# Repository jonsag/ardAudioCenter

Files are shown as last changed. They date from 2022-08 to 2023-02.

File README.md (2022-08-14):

# ardAudioCenter

An arduino used as a center for audio control.  
Selects between inputs, sets volume, balance etc.  
Controls an FM radio receiver.  
Has an LCD screen.  

## Note

This is a work in progress, but should now be working.  

## Parts list (incomplete)

1 x Arduino (I use and Arduino Nano, ElectroKit#41015511)  
1 x TEA5767 FM radio module, ElectroKit#41015747  
1 x DFPlayer Mini  
1 x CD4052B multiplexer, ElectroKit#40360102  
2 x MCP41010-E/P digital potentiometer, ElectroKit#40351010  
1 x LCD screen, 2x16, ElectroKit#41001407  
1 x Serial interface for LCD, ElectroKit#41011443  
2 x Rotary encoder, ElectroKit#41015725

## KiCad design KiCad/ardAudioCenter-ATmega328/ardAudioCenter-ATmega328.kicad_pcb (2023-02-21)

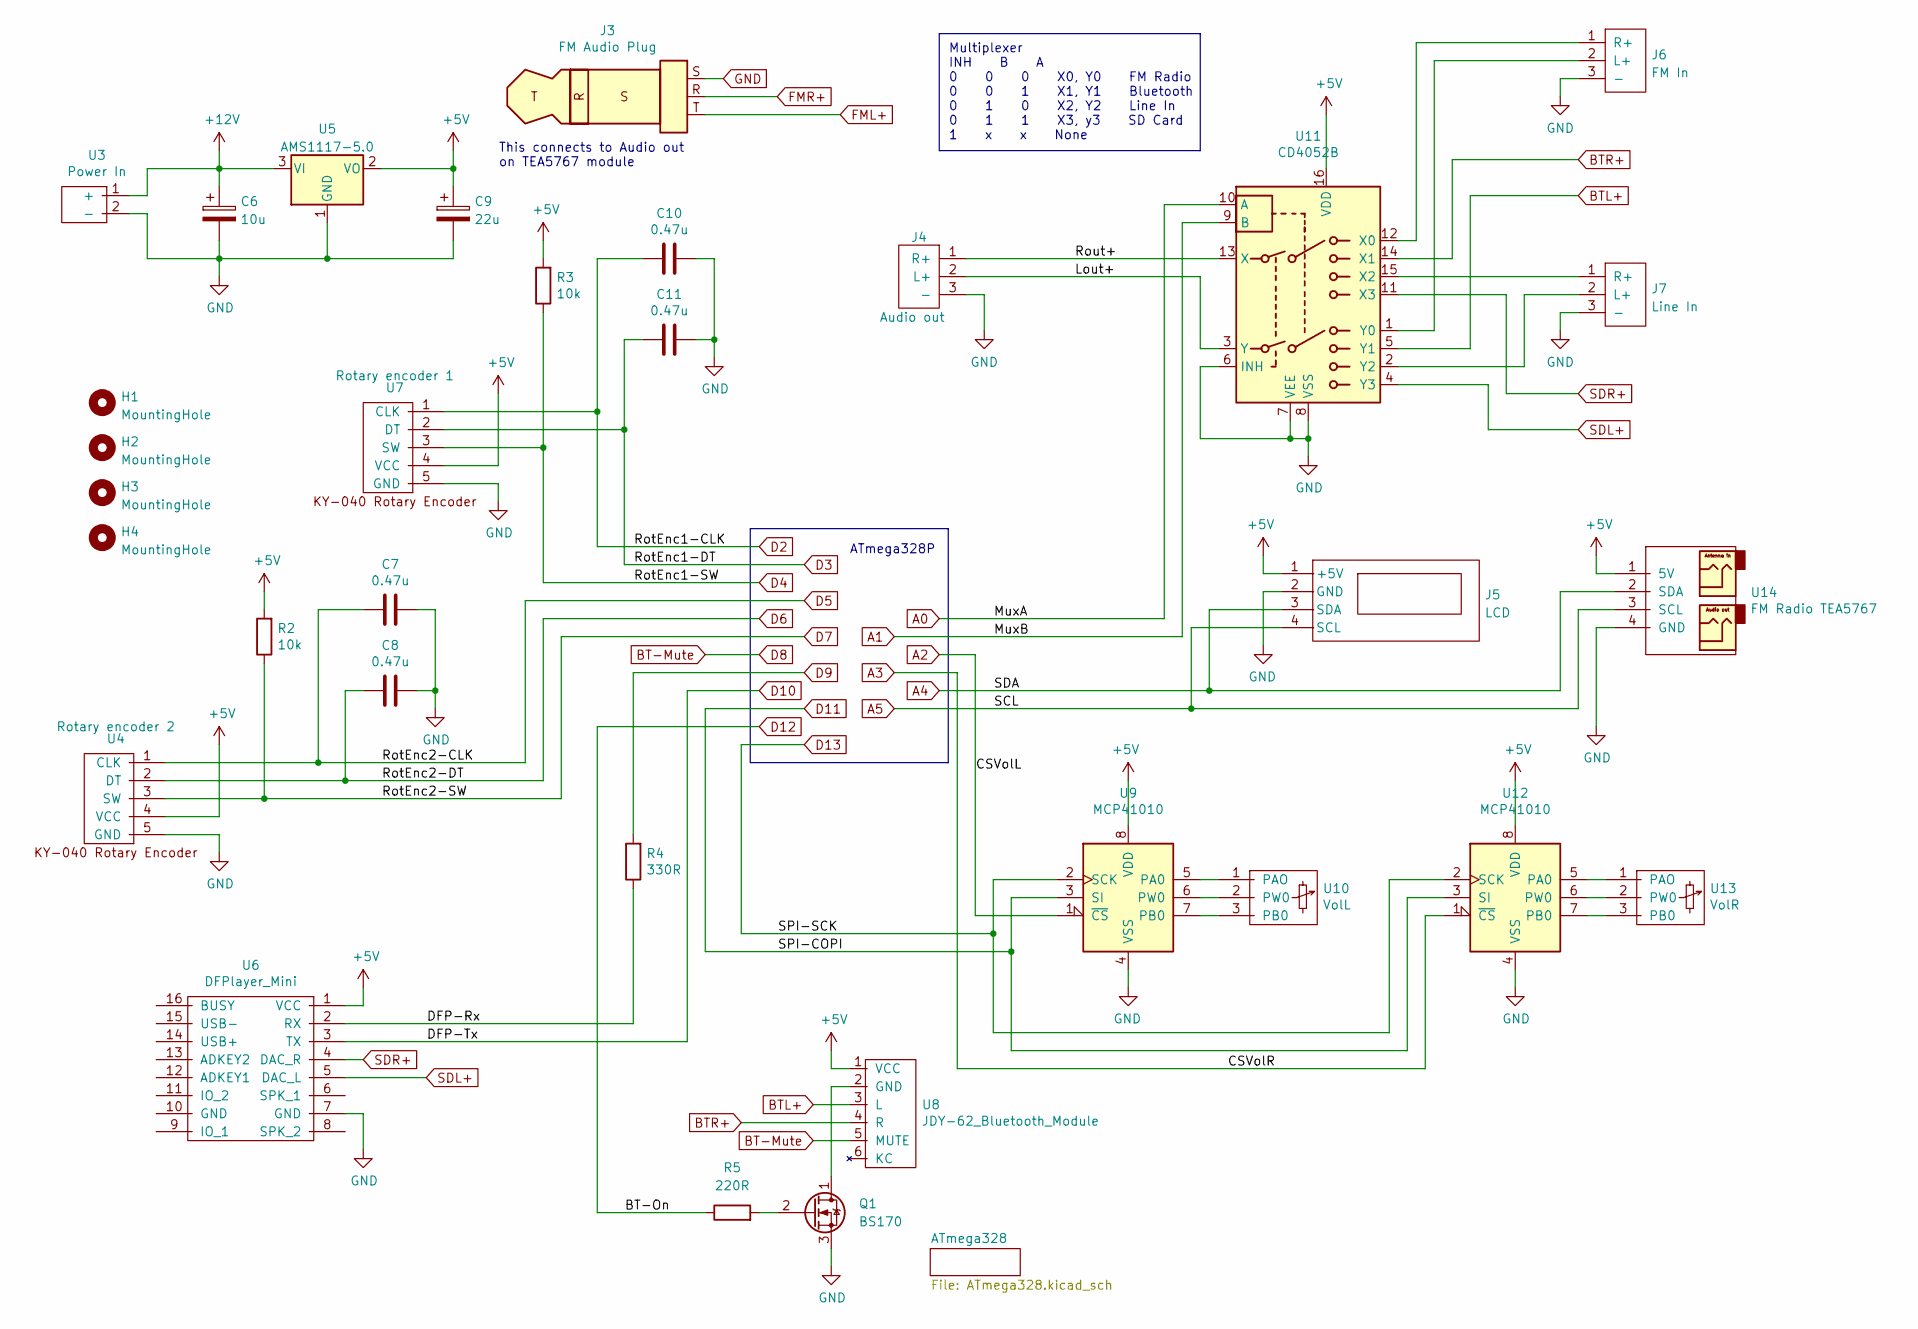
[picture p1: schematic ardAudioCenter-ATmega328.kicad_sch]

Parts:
C6: 10u; CP_Radial_D5.0mm_P2.00mm_larger
C7, C8, C10, C11: 0.47u; C_Disc_D7.5mm_W2.5mm_P5.00mm_larger
C9: 22u; CP_Radial_D5.0mm_P2.00mm_larger
H1, H2, H3, H4: MountingHole; MountingHole_3.5mm
J3: FM Audio Plug
J4: Audio out; 3-pin JST Audio
J5: LCD; 4-pin JST LCD
J6: FM In; 3-pin JST Audio
J7: Line In; 3-pin JST Audio
Q1: BS170; TO-92_Inline_Wide_large
R2, R3: 10k; R_Axial_DIN0207_L6.3mm_D2.5mm_P10.16mm_Horizontal_larger_pa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
R4: 330R; R_Axial_DIN0207_L6.3mm_D2.5mm_P10.16mm_Horizontal_larger_pa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
R5: 220R; R_Axial_DIN0207_L6.3mm_D2.5mm_P10.16mm_Horizontal_larger_pa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
U3: Power In; 2-pole_power_in_screw_terminal
U4: Rotary encoder 2; 5-pin JST Rotary Encoder
U5: AMS1117-5.0; SOT-223-3_TabPin2
U6: DFPlayer_Mini; 8-pin JST DFPlayer Mini
U7: Rotary encoder 1; 5-pin JST Rotary Encoder
U8: JDY-62_Bluetooth_Module; 6-pin JST JDY-62 Bluetooth
U9, U12: MCP41010; DIP-8_W7.62mm_Socket_w_dip_packet_LongPads
U10: VolL; 3-pin JST Potentiometer
U11: CD4052B; DIP-16_W7.62mm_LongPads w socket
U13: VolR; 3-pin JST Potentiometer
U14: FM Radio TEA5767; 4-pin JST TEA5767 FM Radio

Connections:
+5V: C9.1, J5.1 (+5V), R2.2, R3.2, U4.4 (VCC), U5.2 (VO), U6.1 (VCC), U7.4 (VCC), U8.1 (VCC), U9.8 (VDD), U11.16 (VDD), U12.8 (VDD), U14.1 (5V); also elsewhere on the board
+12V: C6.1, U3.1 (+), U5.3 (VI)
/DFP-Rx: R4.1, U6.2 (RX)
/Lout+: J4.2 (L+), U11.3 (Y)
/Rout+: J4.1 (R+), U11.13 (X)
A0: U11.10 (A); also elsewhere on the board
A1: U11.9 (B); also elsewhere on the board
A2: U9.1 (~CS); also elsewhere on the board
A3: U12.1 (~CS); also elsewhere on the board
A4: J5.3 (SDA), U14.2 (SDA); also elsewhere on the board
A5: J5.4 (SCL), U14.3 (SCL); also elsewhere on the board
BT-Mute: U8.5 (MUTE); also elsewhere on the board
BTL+: U8.3 (L), U11.5 (Y1)
BTR+: U8.4 (R), U11.14 (X1)
D2: C10.1, U7.1 (CLK); also elsewhere on the board
D3: C11.2, U7.2 (DT); also elsewhere on the board
D4: R3.1, U7.3 (SW); also elsewhere on the board
D5: C7.1, U4.1 (CLK); also elsewhere on the board
D6: C8.2, U4.2 (DT); also elsewhere on the board
D7: R2.1, U4.3 (SW); also elsewhere on the board
D9: R4.2; also elsewhere on the board
D10: U6.3 (TX); also elsewhere on the board
D11: U9.3 (SI), U12.3 (SI); also elsewhere on the board
D12: R5.1; also elsewhere on the board
D13: U9.2 (SCK), U12.2 (SCK); also elsewhere on the board
GND: C6.2, C7.2, C8.1, C9.2, C10.2, C11.1, J4.3 (-), J5.2 (GND), J6.3 (-), J7.3 (-), Q1.3 (S), U3.2 (-), U4.5 (GND), U5.1 (GND), U6.7 (GND), U7.5 (GND), U9.4 (VSS), U11.6 (INH), U11.7 (VEE), U11.8 (VSS), U12.4 (VSS), U14.4 (GND); also elsewhere on the board
unnamed: J6.1 (R+), U11.12 (X0)
unnamed: J6.2 (L+), U11.1 (Y0)
unnamed: J7.1 (R+), U11.15 (X2)
unnamed: J7.2 (L+), U11.2 (Y2)
unnamed: Q1.1 (D), U8.2 (GND)
unnamed: Q1.2 (G), R5.2
unnamed: U9.5 (PA0), U10.1 (PAO)
unnamed: U9.6 (PW0), U10.2 (PW0)
unnamed: U9.7 (PB0), U10.3 (PB0)
unnamed: U12.5 (PA0), U13.1 (PAO)
unnamed: U12.6 (PW0), U13.2 (PW0)
unnamed: U12.7 (PB0), U13.3 (PB0)
SDL+: U6.5 (DAC_L), U11.4 (Y3)
SDR+: U6.4 (DAC_R), U11.11 (X3)

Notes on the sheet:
This connects to Audio out on TEA5767 module
ATmega328P
Multiplexer INH B A 0 0 0 X0, Y0 FM Radio 0 0 1 X1, Y1 Bluetooth 0 1 0 X2, Y2 Line In 0 1 1 X3, y3 SD Card 1 x x None

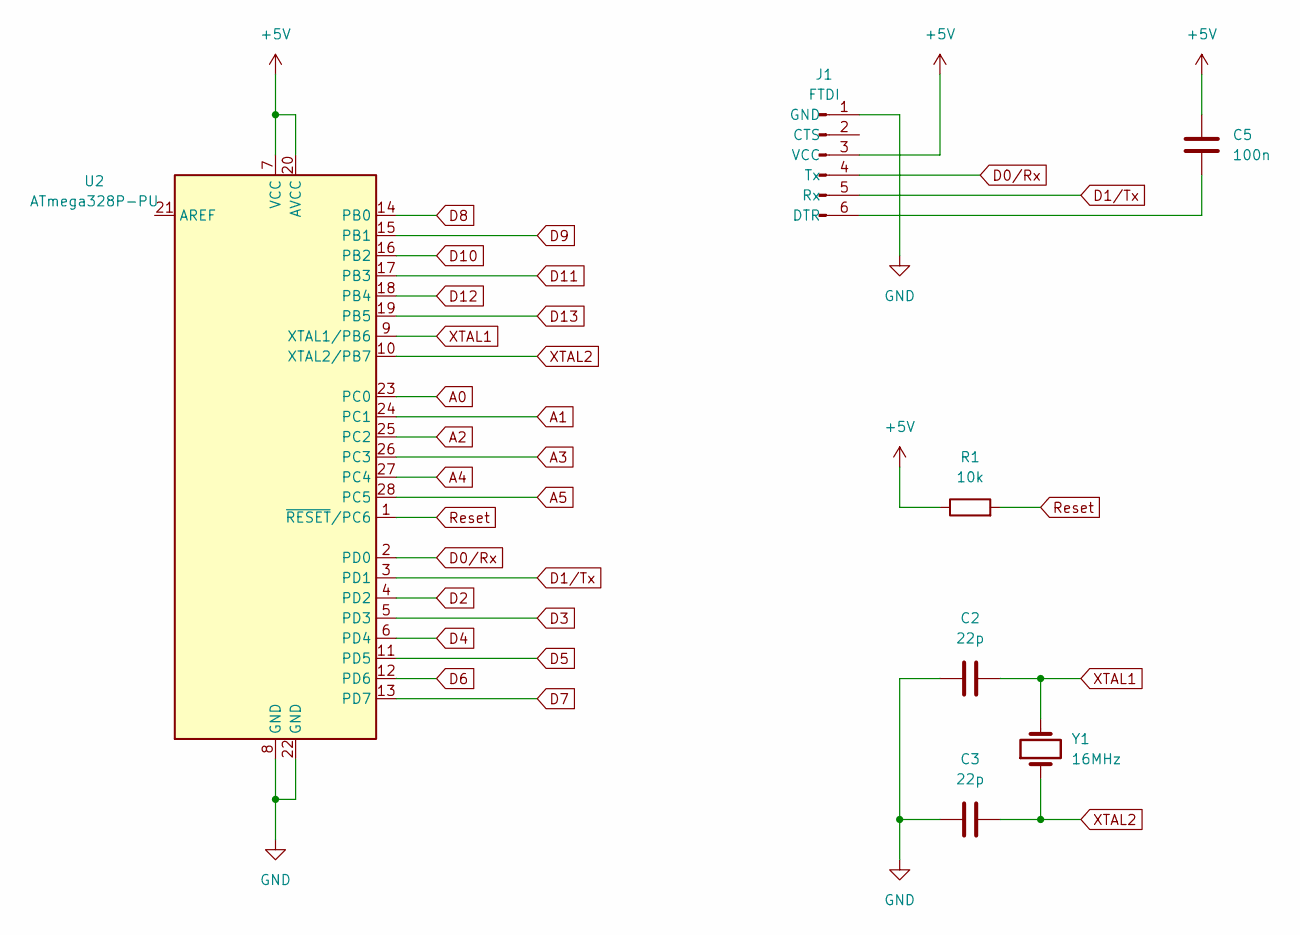
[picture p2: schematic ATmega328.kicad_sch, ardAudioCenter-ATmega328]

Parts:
C2, C3: 22p; C_Disc_D3.0mm_W1.6mm_P2.50mm_larg
C5: 100n; C_Disc_D3.0mm_W1.6mm_P2.50mm_larg
J1: FTDI; 6-pin FTDI Programmer PinSocket large
R1: 10k; R_Axial_DIN0207_L6.3mm_D2.5mm_P10.16mm_Horizontal_larger_pa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
U2: ATmega328P-PU; DIP-28_W7.62mm_LongPads w socket
Y1: 16MHz; Crystal_HC49-4H_Vertical_large

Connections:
+5V: C5.2, J1.3 (VCC), R1.1, U2.7 (VCC), U2.20 (AVCC); also elsewhere on the board
A0: U2.23 (PC0); also elsewhere on the board
A1: U2.24 (PC1); also elsewhere on the board
A2: U2.25 (PC2); also elsewhere on the board
A3: U2.26 (PC3); also elsewhere on the board
A4: U2.27 (PC4); also elsewhere on the board
A5: U2.28 (PC5); also elsewhere on the board
BT-Mute: U2.14 (PB0); also elsewhere on the board
D0/Rx: J1.4 (Tx), U2.2 (PD0)
D1/Tx: J1.5 (Rx), U2.3 (PD1)
D2: U2.4 (PD2); also elsewhere on the board
D3: U2.5 (PD3); also elsewhere on the board
D4: U2.6 (PD4); also elsewhere on the board
D5: U2.11 (PD5); also elsewhere on the board
D6: U2.12 (PD6); also elsewhere on the board
D7: U2.13 (PD7); also elsewhere on the board
D9: U2.15 (PB1); also elsewhere on the board
D10: U2.16 (PB2); also elsewhere on the board
D11: U2.17 (PB3); also elsewhere on the board
D12: U2.18 (PB4); also elsewhere on the board
D13: U2.19 (PB5); also elsewhere on the board
GND: C2.1, C3.1, J1.1 (GND), U2.8 (GND), U2.22 (GND); also elsewhere on the board
unnamed: C5.1, J1.6 (DTR)
Reset: R1.2, U2.1 (~RESET/PC6)
XTAL1: C2.2, U2.9 (XTAL1/PB6), Y1.2
XTAL2: C3.2, U2.10 (XTAL2/PB7), Y1.1

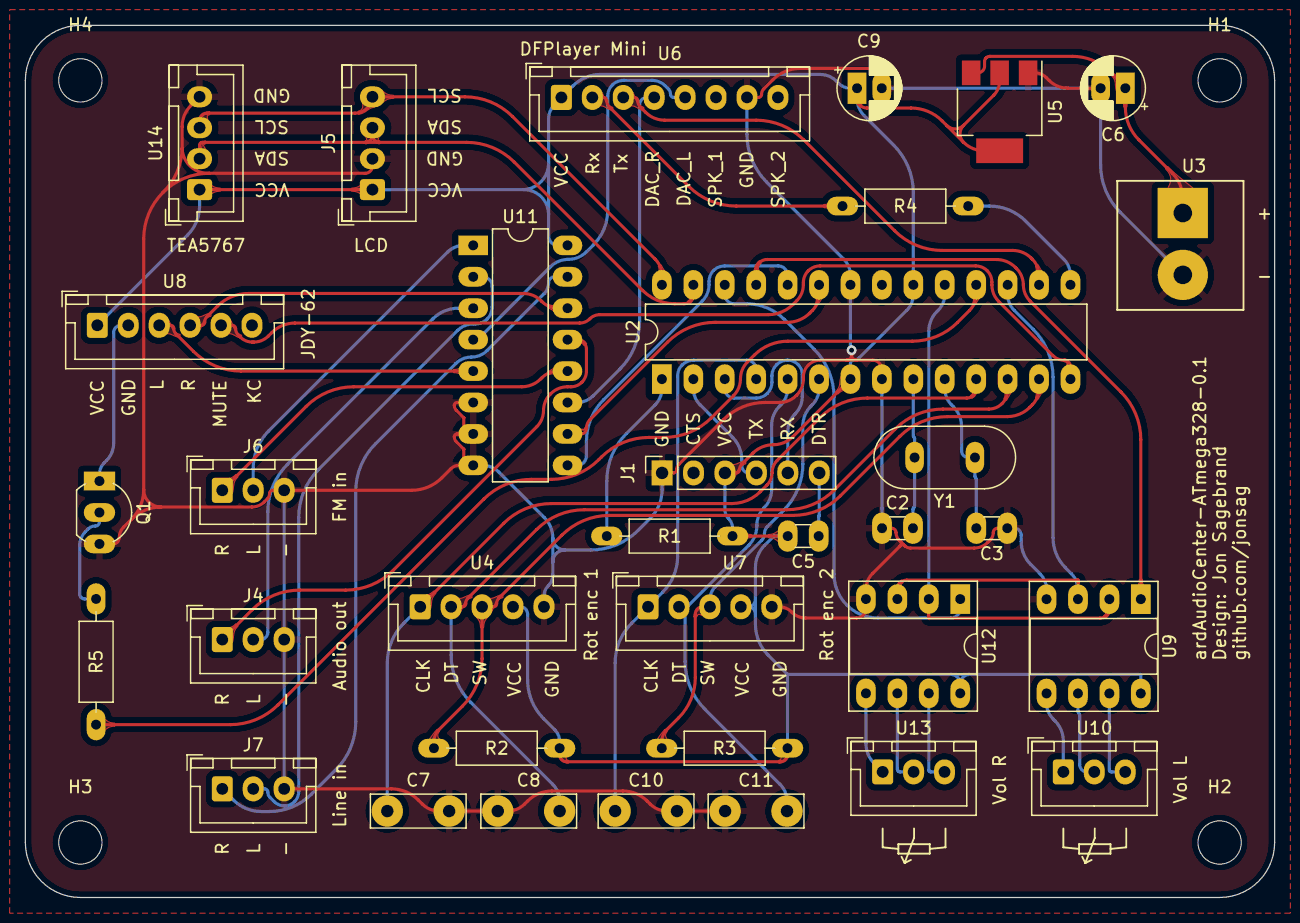
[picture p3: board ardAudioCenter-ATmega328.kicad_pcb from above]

Board: 2 copper layers, 101.0 x 70.5 mm, 38 parts (0 on the bottom side), 46 nets.

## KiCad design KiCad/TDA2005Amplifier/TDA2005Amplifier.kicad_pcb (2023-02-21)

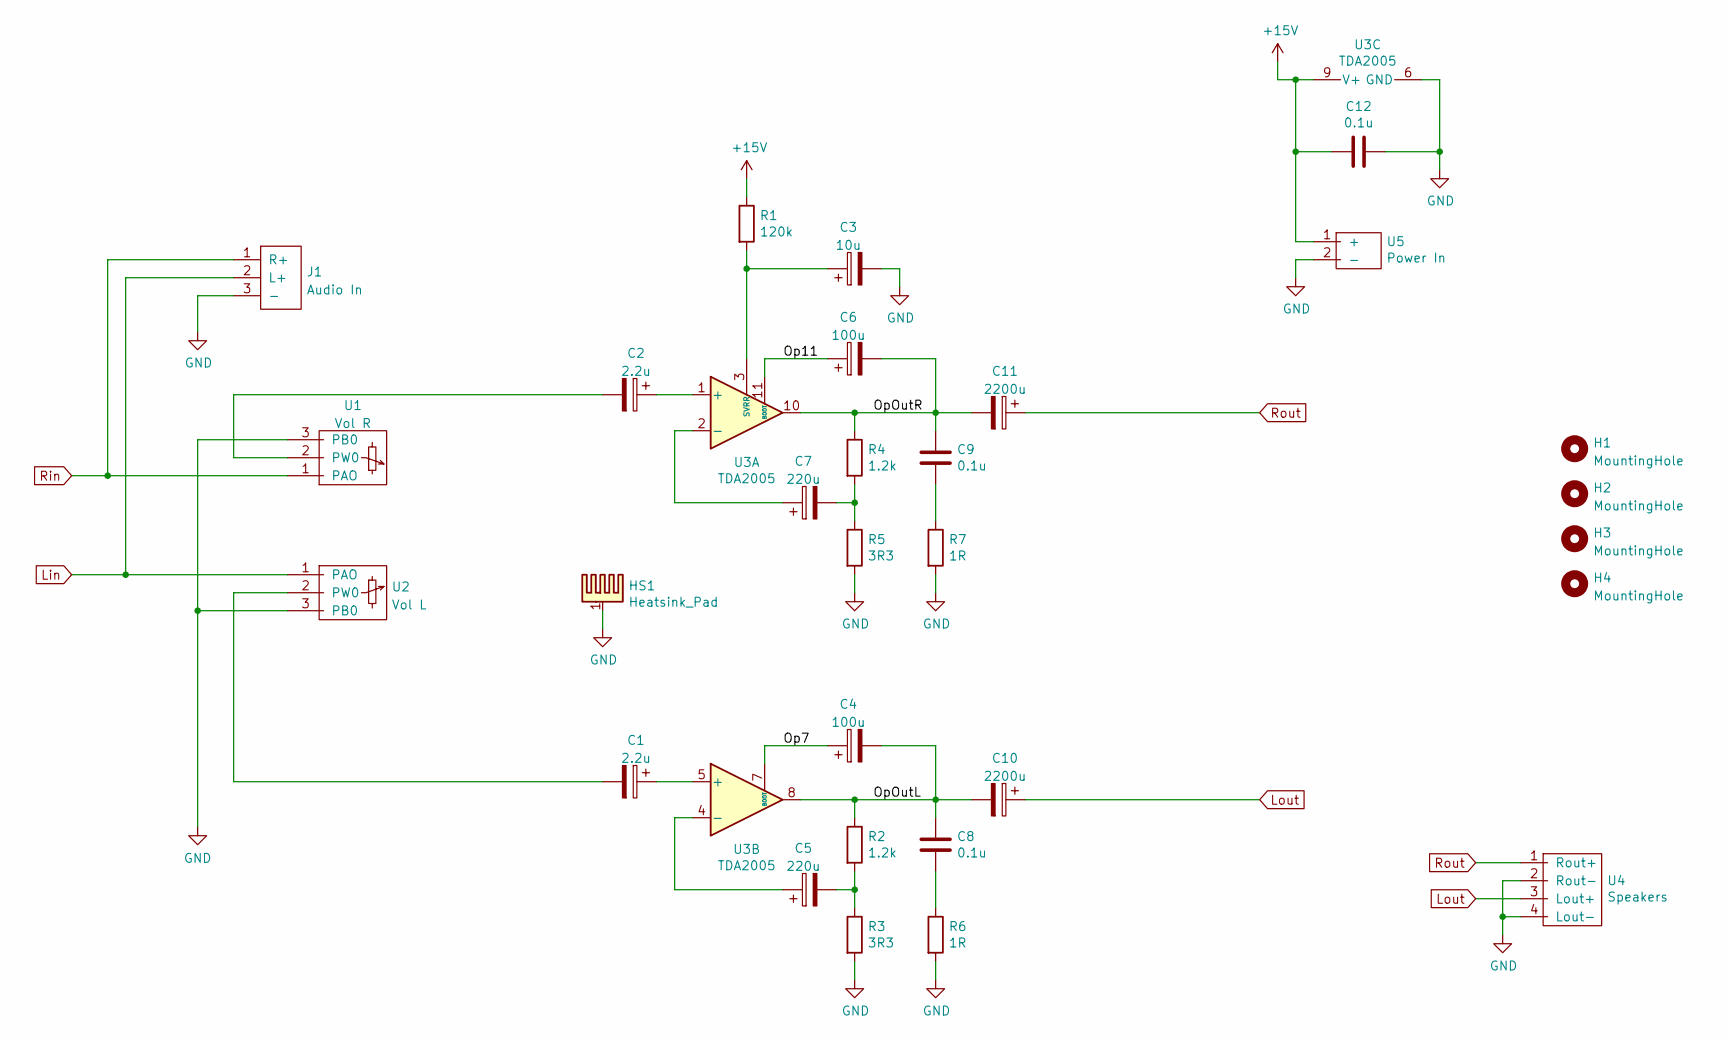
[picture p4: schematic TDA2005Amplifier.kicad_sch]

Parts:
C1, C2: 2.2u; CP_Radial_D5.0mm_P2.00mm_larger
C3: 10u; CP_Radial_D5.0mm_P2.00mm_larger
C4, C6: 100u; CP_Radial_D5.0mm_P2.50mm_larger_pads
C5, C7: 220u; CP_Radial_D8.0mm_P3.50mm_large
C8, C9, C12: 0.1u; C_Disc_D7.5mm_W2.5mm_P5.00mm_larger
C10, C11: 2200u; CP_Radial_D13.0mm_P5.00mm_larger
H1, H2, H3, H4: MountingHole; MountingHole_3.2mm_M3
HS1: Heatsink_Pad; EK-41002859
J1: Audio In; 3-pin JST Audio
R1: 120k; R_Axial_DIN0414_L11.9mm_D4.5mm_P15.24mm_Horizontal_larger
R2, R4: 1.2k; R_Axial_DIN0414_L11.9mm_D4.5mm_P15.24mm_Horizontal_larger
R3, R5: 3R3; R_Axial_DIN0414_L11.9mm_D4.5mm_P15.24mm_Horizontal_larger
R6, R7: 1R; R_Axial_DIN0414_L11.9mm_D4.5mm_P15.24mm_Horizontal_larger
U1: Vol R; 3-pin JST Potentiometer
U2: Vol L; 3-pin JST Potentiometer
U3: TDA2005; TO-220-11_P3.4x5.08mm_StaggerOdd_Lead4.85mm_Vertical_large
U4: Speakers; 4-pole_screw_terminal_RL_output
U5: Power In; 2-pole_power_in_screw_terminal

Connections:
+15V: C12.2, R1.1, U3.9 (V+), U5.1 (+)
/Op7: C4.1, U3.7 (BOOT)
/Op11: C6.1, U3.11 (BOOT)
/OpOutL: C4.2, C8.1, C10.2, R2.1, U3.8
/OpOutR: C6.2, C9.1, C11.2, R4.1, U3.10
GND: C3.2, C12.1, HS1.1, J1.3 (-), R3.2, R5.2, R6.2, R7.2, U1.3 (PB0), U2.3 (PB0), U3.6 (GND), U4.2 (Rout-), U4.4 (Lout-), U5.2 (-)
Lin: J1.2 (L+), U2.1 (PAO)
Lout: C10.1, U4.3 (Lout+)
unnamed: C1.1, U3.5 (+)
unnamed: C1.2, U2.2 (PW0)
unnamed: C2.1, U3.1 (+)
unnamed: C2.2, U1.2 (PW0)
unnamed: C3.1, R1.2, U3.3 (SVRR)
unnamed: C5.1, U3.4 (-)
unnamed: C5.2, R2.2, R3.1
unnamed: C7.1, U3.2 (-)
unnamed: C7.2, R4.2, R5.1
unnamed: C8.2, R6.1
unnamed: C9.2, R7.1
Rin: J1.1 (R+), U1.1 (PAO)
Rout: C11.1, U4.1 (Rout+)

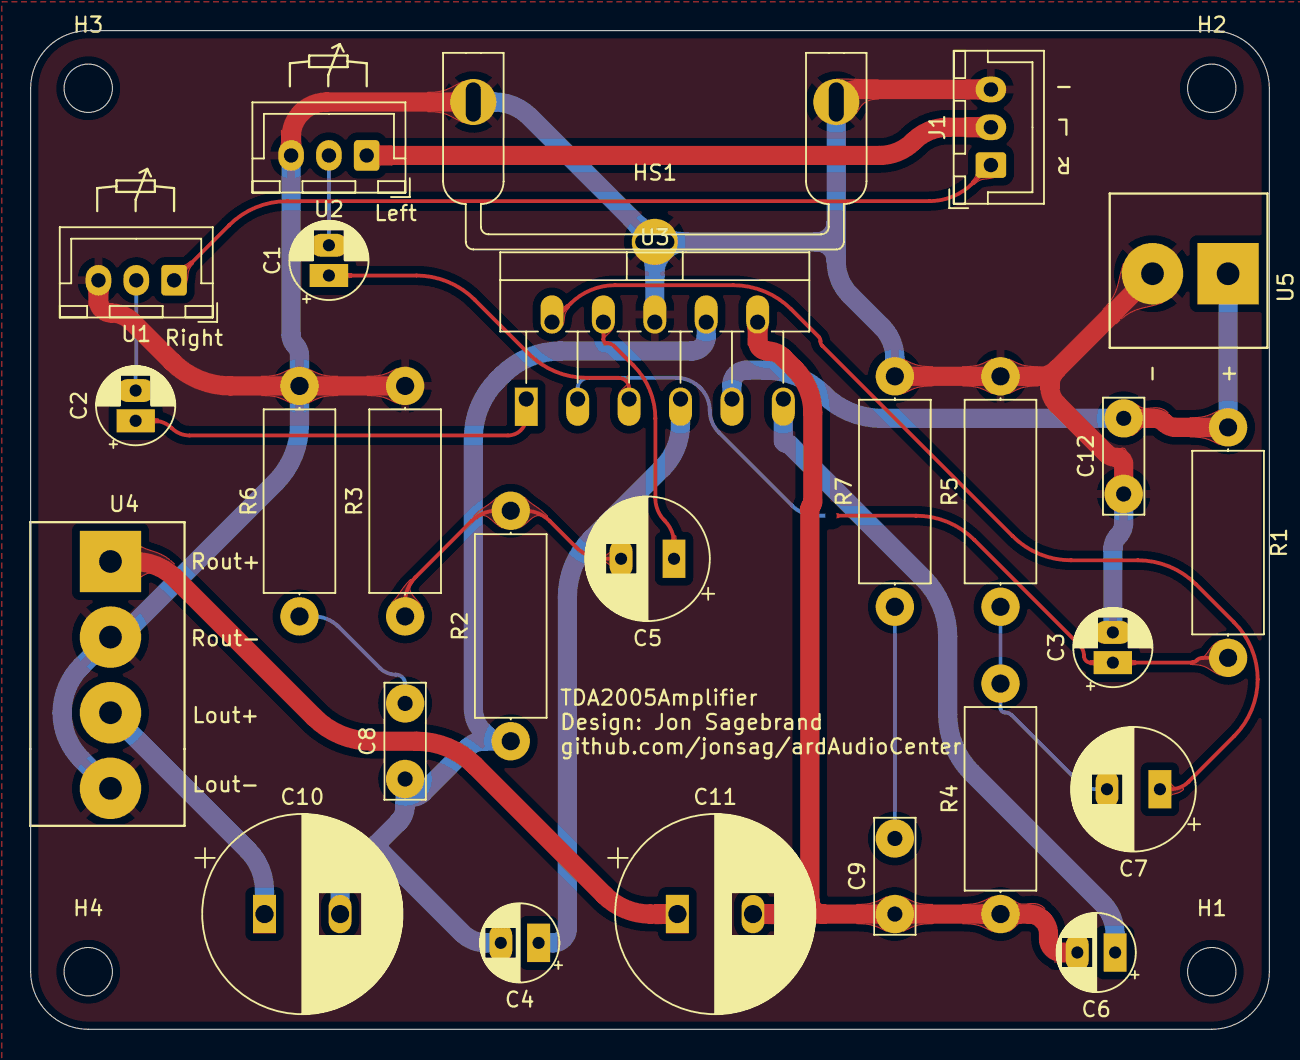
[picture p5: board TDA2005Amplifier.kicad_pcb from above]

Board: 2 copper layers, 81.9 x 66.0 mm, 30 parts (0 on the bottom side), 21 nets.

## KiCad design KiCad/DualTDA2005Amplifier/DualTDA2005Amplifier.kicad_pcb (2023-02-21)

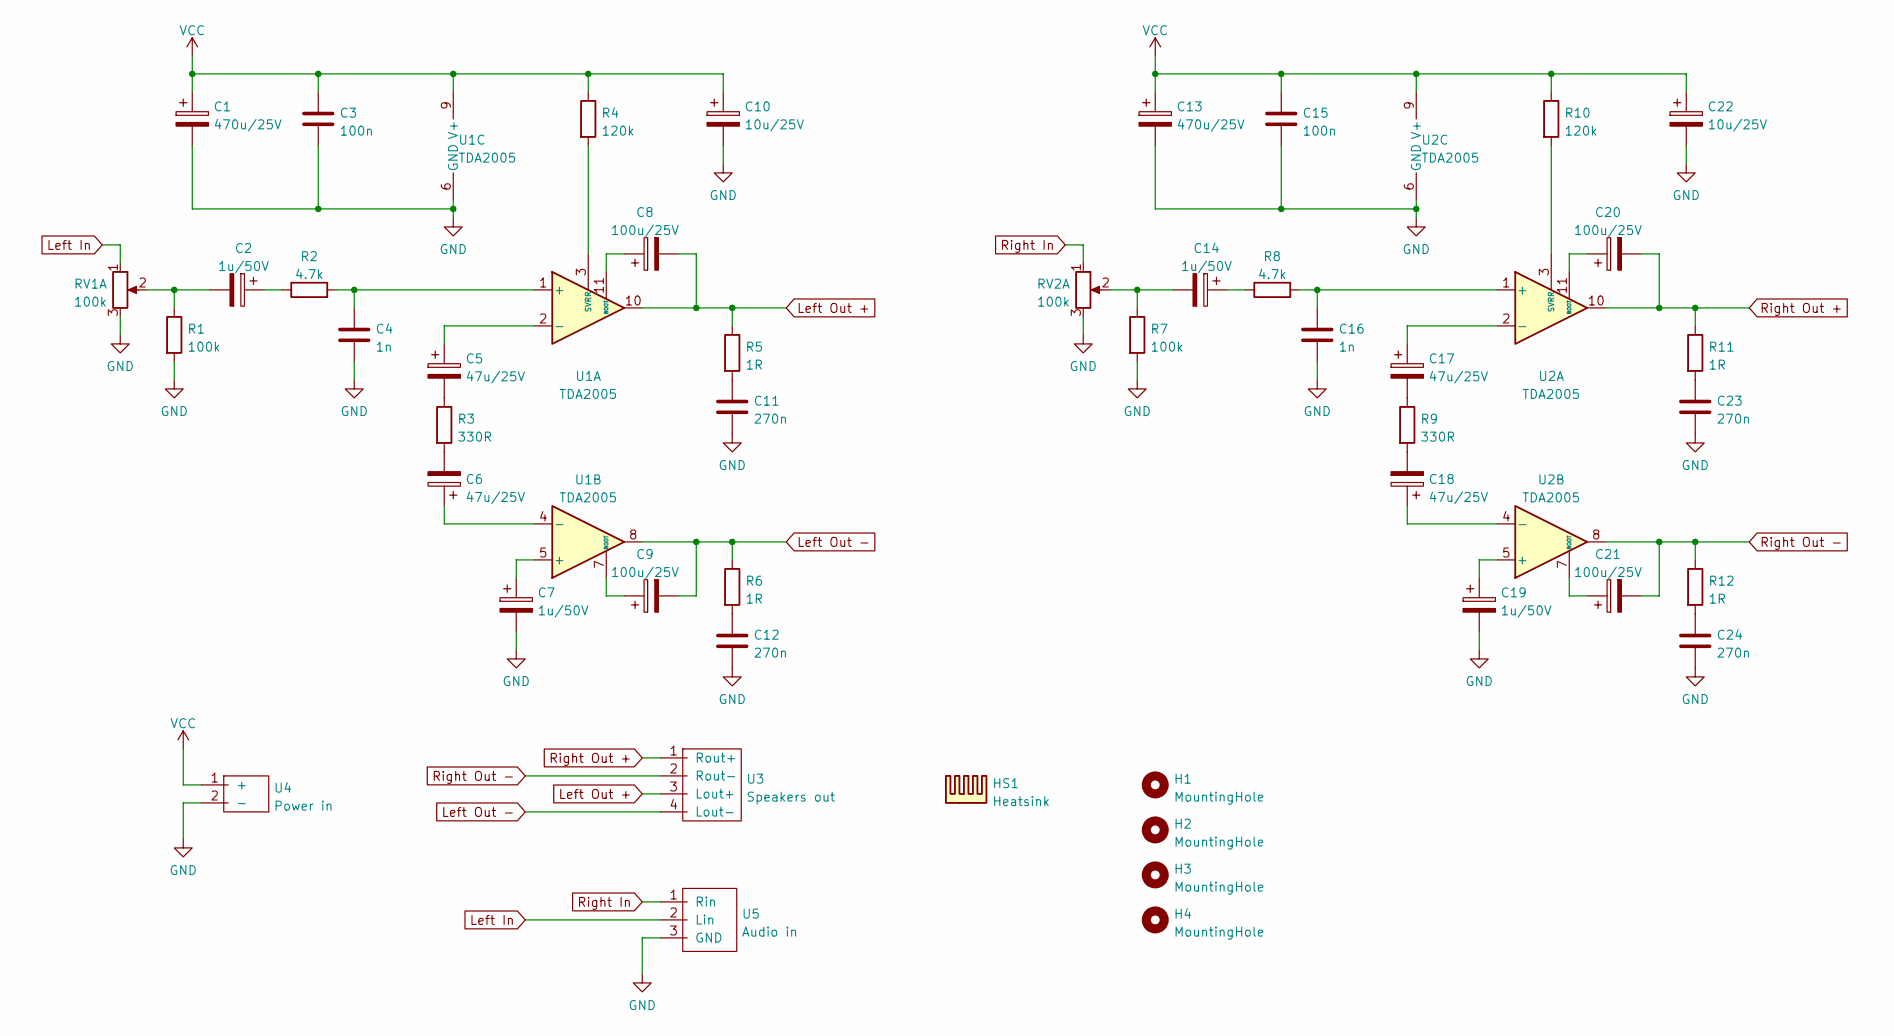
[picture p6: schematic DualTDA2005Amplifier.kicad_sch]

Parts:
C1, C13: 470u/25V; CP_Radial_D10.0mm_P5.00mm_larger
C2, C7, C14, C19: 1u/50V; CP_Radial_D5.0mm_P2.00mm_larger
C3, C15: 100n; C_Rect_L7.2mm_W2.5mm_P5.00mm_FKS2_FKP2_MKS2_MKP2 large
C4, C16: 1n; C_Rect_L7.2mm_W2.5mm_P5.00mm_FKS2_FKP2_MKS2_MKP2 large
C5, C6, C17, C18: 47u/25V; CP_Radial_D5.0mm_P2.00mm_larger
C8, C9, C20, C21: 100u/25V; CP_Radial_D6.3mm_P2.50mm_large
C10, C22: 10u/25V; CP_Radial_D5.0mm_P2.00mm_larger
C11, C12, C23, C24: 270n; C_Rect_L7.2mm_W3.5mm_P5.00mm_FKS2_FKP2_MKS2_MKP2 large
H1, H2, H3, H4: MountingHole; MountingHole_3.2mm_M3
HS1: Heatsink; Heatsink SK81 100x37.5x15
R1, R7: 100k; R_Axial_DIN0207_L6.3mm_D2.5mm_P10.16mm_Horizontal_larger_pa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
R2, R8: 4.7k; R_Axial_DIN0207_L6.3mm_D2.5mm_P10.16mm_Horizontal_larger_pa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
R3, R9: 330R; R_Axial_DIN0207_L6.3mm_D2.5mm_P10.16mm_Horizontal_larger_pa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
R4, R10: 120k; R_Axial_DIN0207_L6.3mm_D2.5mm_P10.16mm_Horizontal_larger_pa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
R5, R6, R11, R12: 1R; R_Axial_DIN0207_L6.3mm_D2.5mm_P10.16mm_Horizontal_larger_pa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
RV1, RV2: 100k; 3-pin JST Potentiometer
U1, U2: TDA2005; TO-220-11_P3.4x5.08mm_StaggerOdd_Lead4.85mm_Vertical_large
U3: Speakers out; 4-pole_screw_terminal_RL_output
U4: Power in; 2-pole_power_in_screw_terminal
U5: Audio in; 3-pin JST Audio

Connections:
GND: C1.2, C3.2, C4.2, C7.2, C10.2, C11.2, C12.2, C13.2, C15.2, C16.2, C19.2, C22.2, C23.2, C24.2, R1.2, R7.2, RV1.3, RV2.3, U1.6 (GND), U2.6 (GND), U4.2 (-), U5.3 (GND)
Left In: RV1.1, U5.2 (Lin)
Left Out +: C8.2, R5.1, U1.10, U3.3 (Lout+)
Left Out -: C9.2, R6.1, U1.8, U3.4 (Lout-)
unnamed: C2.1, R2.1
unnamed: C2.2, R1.1, RV1.2
unnamed: C4.1, R2.2, U1.1 (+)
unnamed: C5.1, U1.2 (-)
unnamed: C5.2, R3.1
unnamed: C6.1, U1.4 (-)
unnamed: C6.2, R3.2
unnamed: C7.1, U1.5 (+)
unnamed: C8.1, U1.11 (BOOT)
unnamed: C9.1, U1.7 (BOOT)
unnamed: C11.1, R5.2
unnamed: C12.1, R6.2
unnamed: C14.1, R8.1
unnamed: C14.2, R7.1, RV2.2
unnamed: C16.1, R8.2, U2.1 (+)
unnamed: C17.1, U2.2 (-)
unnamed: C17.2, R9.1
unnamed: C18.1, U2.4 (-)
unnamed: C18.2, R9.2
unnamed: C19.1, U2.5 (+)
unnamed: C20.1, U2.11 (BOOT)
unnamed: C21.1, U2.7 (BOOT)
unnamed: C23.1, R11.2
unnamed: C24.1, R12.2
unnamed: R4.2, U1.3 (SVRR)
unnamed: R10.2, U2.3 (SVRR)
Right In: RV2.1, U5.1 (Rin)
Right Out +: C20.2, R11.1, U2.10, U3.1 (Rout+)
Right Out -: C21.2, R12.1, U2.8, U3.2 (Rout-)
VCC: C1.1, C3.1, C10.1, C13.1, C15.1, C22.1, R4.1, R10.1, U1.9 (V+), U2.9 (V+), U4.1 (+)

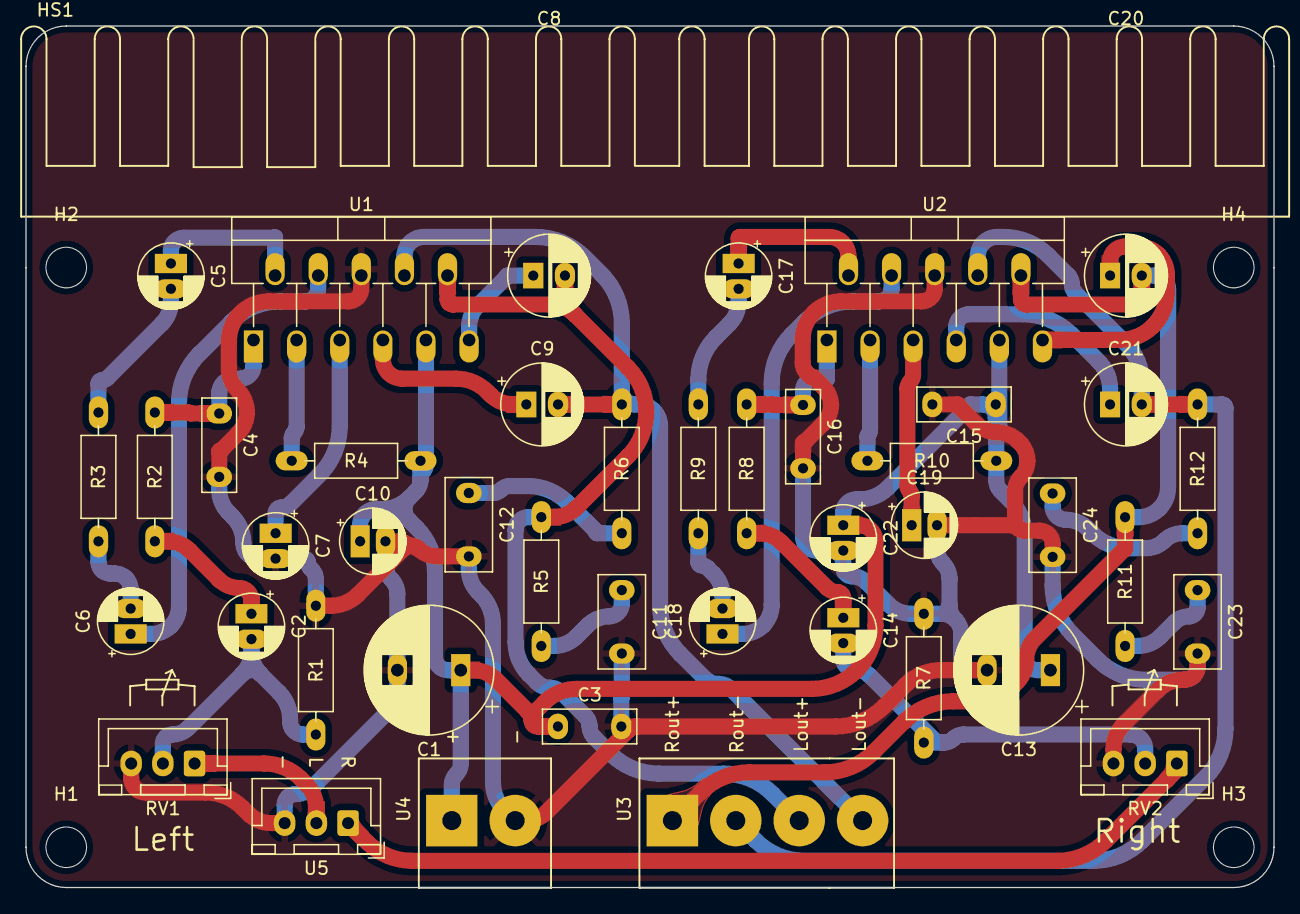
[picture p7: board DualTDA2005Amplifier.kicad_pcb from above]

Board: 2 copper layers, 98.4 x 67.9 mm, 48 parts (0 on the bottom side), 34 nets.

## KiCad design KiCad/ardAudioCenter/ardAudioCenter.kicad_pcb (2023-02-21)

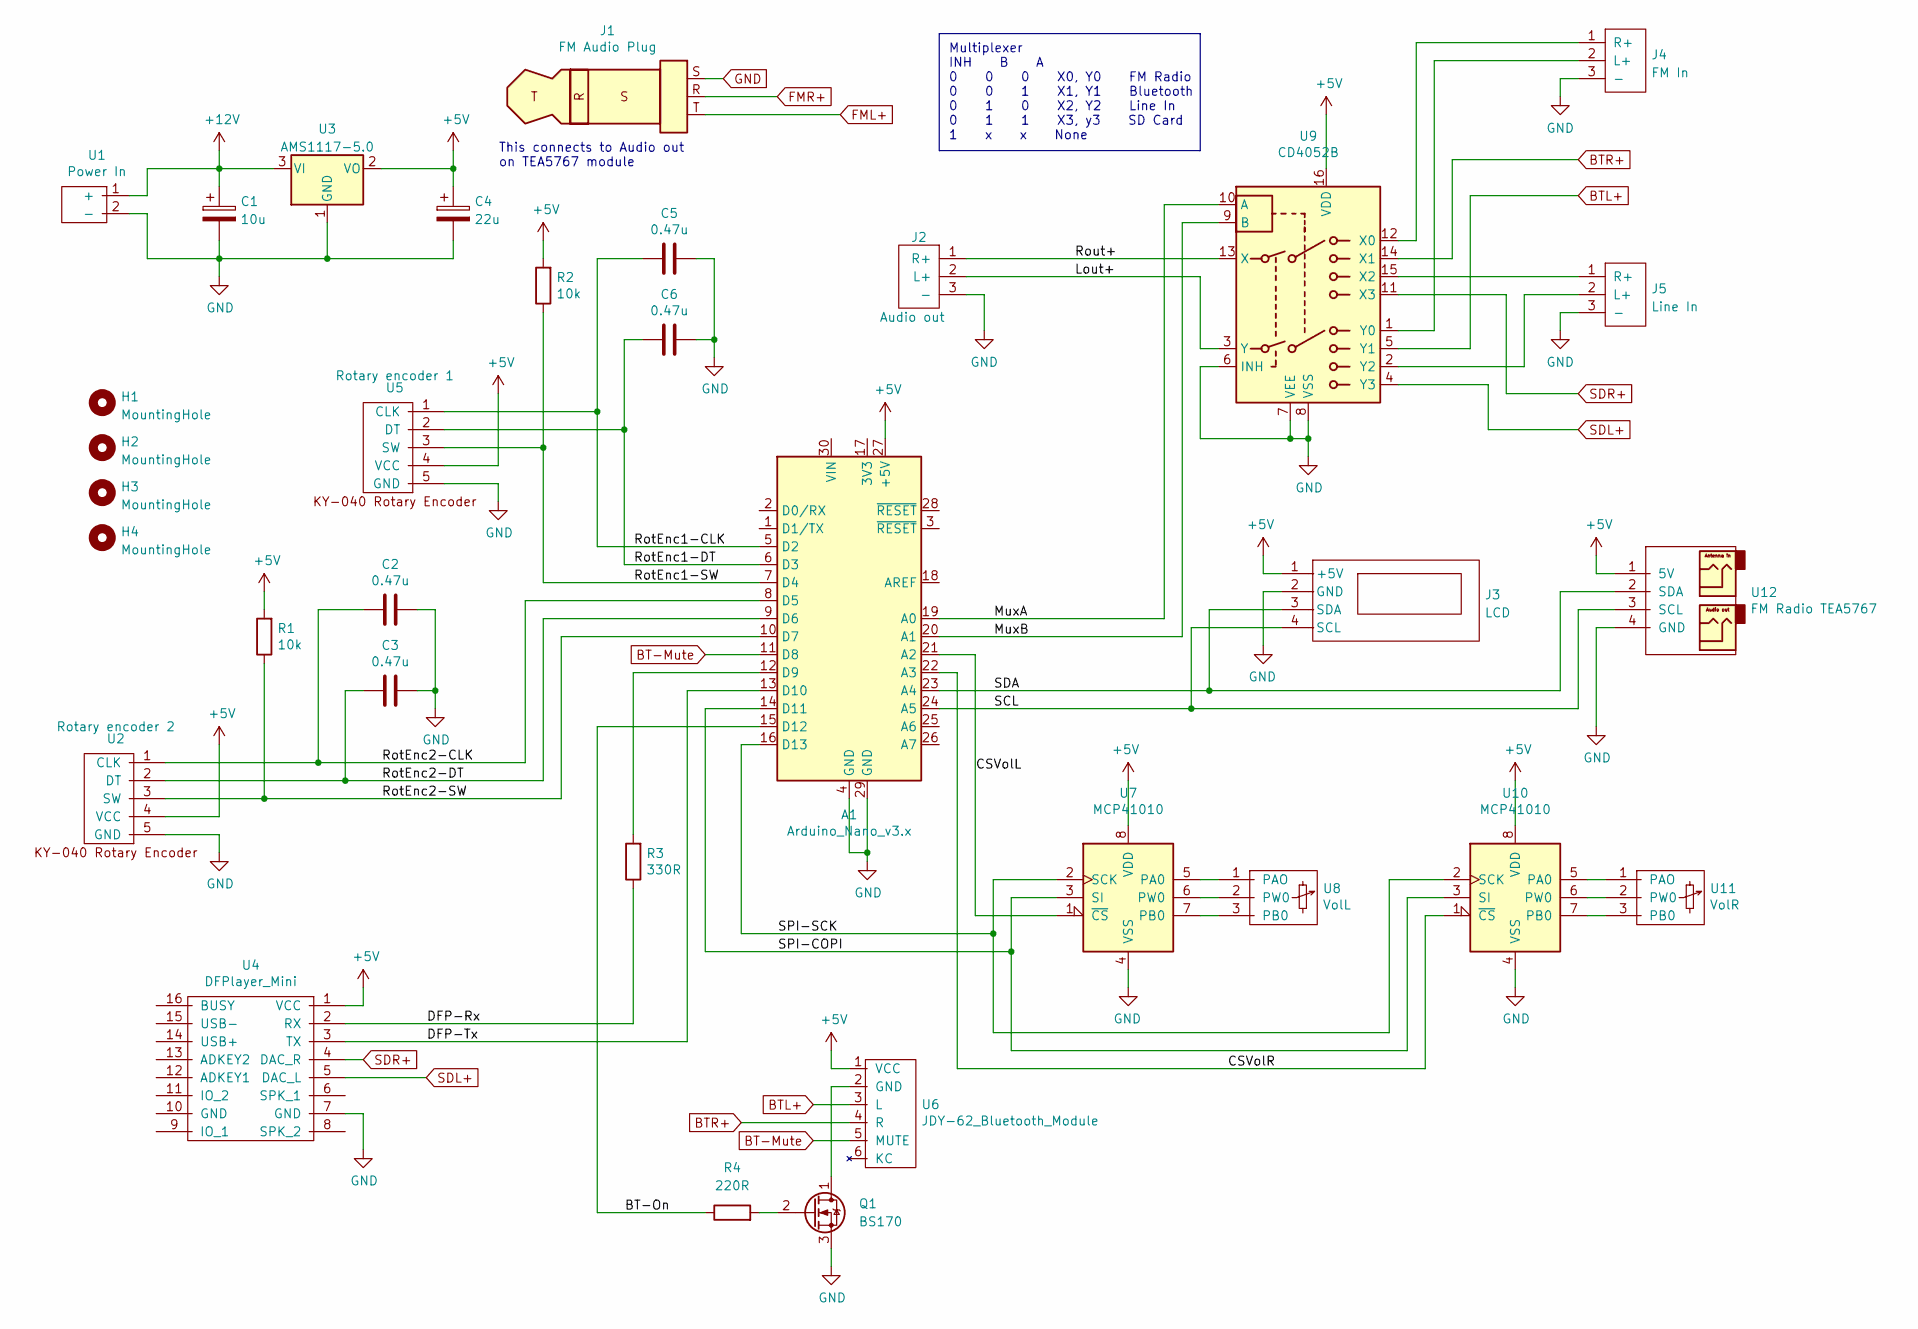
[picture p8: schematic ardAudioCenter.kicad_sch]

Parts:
A1: Arduino_Nano_v3.x; Arduino_Nano_WithMountingHoles_larger
C1: 10u; CP_Radial_D5.0mm_P2.00mm_larger
C2, C3, C5, C6: 0.47u; C_Disc_D7.5mm_W2.5mm_P5.00mm_larger
C4: 22u; CP_Radial_D5.0mm_P2.00mm_larger
H1, H2, H3, H4: MountingHole; MountingHole_3.5mm
J1: FM Audio Plug
J2: Audio out; 3-pin JST Audio
J3: LCD; 4-pin JST LCD
J4: FM In; 3-pin JST Audio
J5: Line In; 3-pin JST Audio
Q1: BS170; TO-92_Inline_Wide_large
R1, R2: 10k; R_Axial_DIN0207_L6.3mm_D2.5mm_P10.16mm_Horizontal_larger_pa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
R3: 330R; R_Axial_DIN0207_L6.3mm_D2.5mm_P10.16mm_Horizontal_larger_pa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
R4: 220R; R_Axial_DIN0207_L6.3mm_D2.5mm_P10.16mm_Horizontal_larger_pa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
U1: Power In; 2-pole_power_in_screw_terminal
U2: Rotary encoder 2; 5-pin JST Rotary Encoder
U3: AMS1117-5.0; SOT-223-3_TabPin2
U4: DFPlayer_Mini; 8-pin JST DFPlayer Mini
U5: Rotary encoder 1; 5-pin JST Rotary Encoder
U6: JDY-62_Bluetooth_Module; 6-pin JST JDY-62 Bluetooth
U7, U10: MCP41010; DIP-8_W7.62mm_Socket_w_dip_packet_LongPads
U8: VolL; 3-pin JST Potentiometer
U9: CD4052B; DIP-16_W7.62mm_LongPads w socket
U11: VolR; 3-pin JST Potentiometer
U12: FM Radio TEA5767; 4-pin JST TEA5767 FM Radio

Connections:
+5V: A1.27 (+5V), C4.1, J3.1 (+5V), R1.2, R2.2, U2.4 (VCC), U3.2 (VO), U4.1 (VCC), U5.4 (VCC), U6.1 (VCC), U7.8 (VDD), U9.16 (VDD), U10.8 (VDD), U12.1 (5V)
+12V: C1.1, U1.1 (+), U3.3 (VI)
/BT-On: A1.15 (D12), R4.1
/CSVolL: A1.21 (A2), U7.1 (~CS)
/CSVolR: A1.22 (A3), U10.1 (~CS)
/DFP-Rx: R3.1, U4.2 (RX)
/DFP-Tx: A1.13 (D10), U4.3 (TX)
/Lout+: J2.2 (L+), U9.3 (Y)
/MuxA: A1.19 (A0), U9.10 (A)
/MuxB: A1.20 (A1), U9.9 (B)
/RotEnc1-CLK: A1.5 (D2), C5.1, U5.1 (CLK)
/RotEnc1-DT: A1.6 (D3), C6.2, U5.2 (DT)
/RotEnc1-SW: A1.7 (D4), R2.1, U5.3 (SW)
/RotEnc2-CLK: A1.8 (D5), C2.1, U2.1 (CLK)
/RotEnc2-DT: A1.9 (D6), C3.2, U2.2 (DT)
/RotEnc2-SW: A1.10 (D7), R1.1, U2.3 (SW)
/Rout+: J2.1 (R+), U9.13 (X)
/SCL: A1.24 (A5), J3.4 (SCL), U12.3 (SCL)
/SDA: A1.23 (A4), J3.3 (SDA), U12.2 (SDA)
/SPI-COPI: A1.14 (D11), U7.3 (SI), U10.3 (SI)
/SPI-SCK: A1.16 (D13), U7.2 (SCK), U10.2 (SCK)
BT-Mute: A1.11 (D8), U6.5 (MUTE)
BTL+: U6.3 (L), U9.5 (Y1)
BTR+: U6.4 (R), U9.14 (X1)
GND: A1.4 (GND), A1.29 (GND), C1.2, C2.2, C3.1, C4.2, C5.2, C6.1, J2.3 (-), J3.2 (GND), J4.3 (-), J5.3 (-), Q1.3 (S), U1.2 (-), U2.5 (GND), U3.1 (GND), U4.7 (GND), U5.5 (GND), U7.4 (VSS), U9.6 (INH), U9.7 (VEE), U9.8 (VSS), U10.4 (VSS), U12.4 (GND)
unnamed: A1.12 (D9), R3.2
unnamed: J4.1 (R+), U9.12 (X0)
unnamed: J4.2 (L+), U9.1 (Y0)
unnamed: J5.1 (R+), U9.15 (X2)
unnamed: J5.2 (L+), U9.2 (Y2)
unnamed: Q1.2 (G), R4.2
unnamed: Q1.1 (D), U6.2 (GND)
unnamed: U7.5 (PA0), U8.1 (PAO)
unnamed: U7.6 (PW0), U8.2 (PW0)
unnamed: U7.7 (PB0), U8.3 (PB0)
unnamed: U10.5 (PA0), U11.1 (PAO)
unnamed: U10.6 (PW0), U11.2 (PW0)
unnamed: U10.7 (PB0), U11.3 (PB0)
SDL+: U4.5 (DAC_L), U9.4 (Y3)
SDR+: U4.4 (DAC_R), U9.11 (X3)

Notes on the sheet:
This connects to Audio out on TEA5767 module
Multiplexer INH B A 0 0 0 X0, Y0 FM Radio 0 0 1 X1, Y1 Bluetooth 0 1 0 X2, Y2 Line In 0 1 1 X3, y3 SD Card 1 x x None

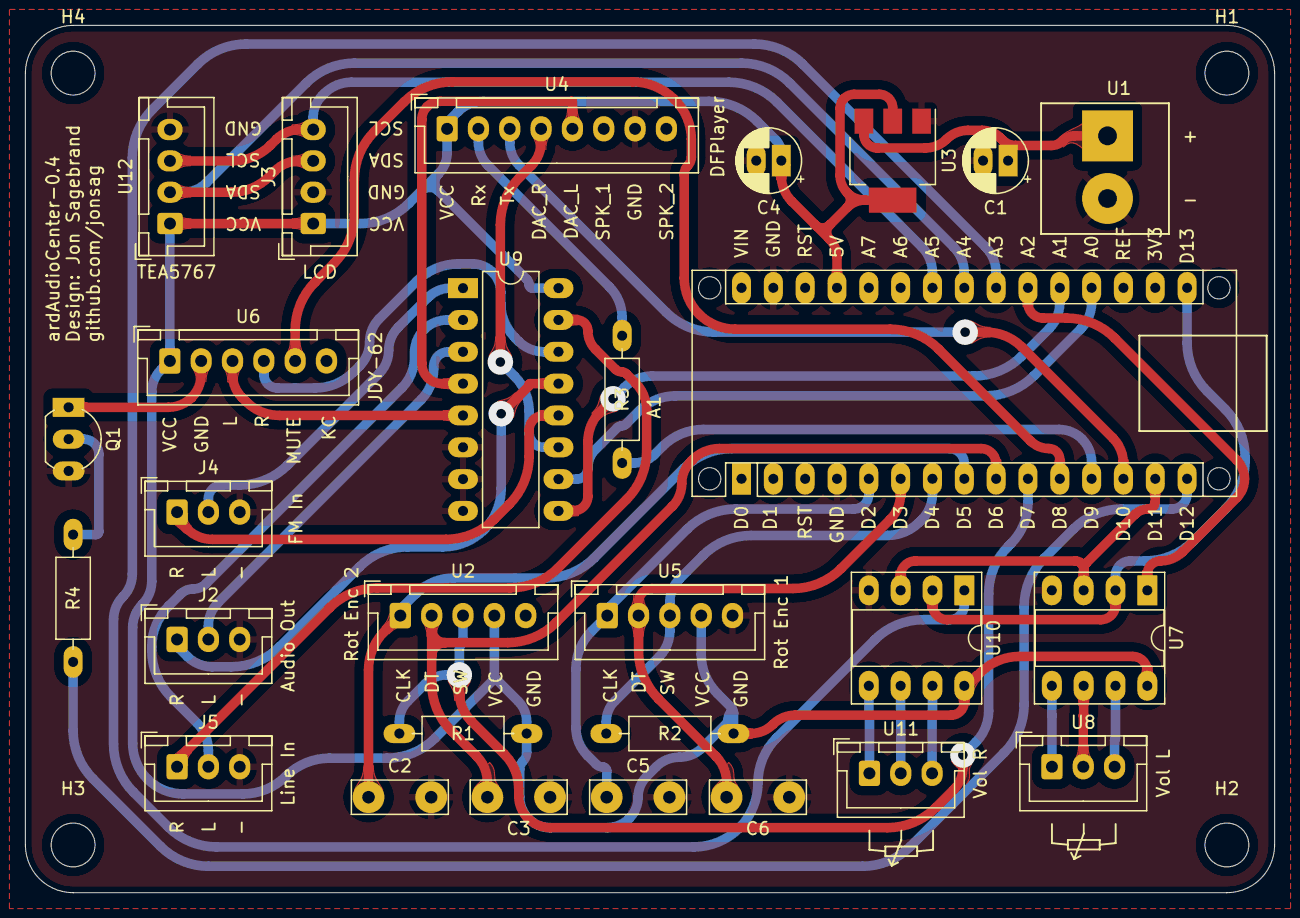
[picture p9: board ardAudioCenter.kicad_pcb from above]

Board: 2 copper layers, 99.7 x 69.2 mm, 32 parts (0 on the bottom side), 40 nets.

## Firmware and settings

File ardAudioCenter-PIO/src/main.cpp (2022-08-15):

#include "Arduino.h"

#include "configuration.h" // sets all variables

#include "lcd.h"          // manages all info on LCD
#include "radioTEA5767.h" // control the FM radio module

#if DFPLAYER
#include "sdCard.h" // control the DFPlayer Mini SD Card module
#endif

#include "buttons.h" // handle button presses
#include "sources.h" // sets source
#include "volume.h"  // sets volume

void setup()
{
  /*******************************
    Start wire, I2C
  *******************************/
  // Wire.begin(SDApin, SCLpin);

  /*******************************
    Start LCD
  *******************************/
  lcd.begin(); // initialize the lcd
  lcd.backlight();
  lcd.setCursor(0, 0); // print name of this program and boot message to the LCD
  lcd.print(programName);
  lcd.setCursor(0, 1);
  lcd.print("Booting ...     ");

  delay(bootDelay); // delay to be able to see message on LCD

  /*******************************
    Start serial
  *******************************/
#if DEBUG || INFO
  lcd.setCursor(0, 1);
  lcd.print("Starting serial ...");

  Serial.begin(serialSpeed);

  delay(bootDelay); // delay to be able to see message on LCD
#endif

  /*******************************
    Print start information
  *******************************/
  infoMessln(programName);
  infoMessln(date);
  infoMessln("by ");
  infoMessln(author);
  infoMessln(email);

  debugMess("Number of sources: ");
  debugMessln(sizeof(sources) / sizeof(sources[0]));
  debugMessln();

  debugMess("Source selected: ");
  debugMessln(sourceNo);
  debugMessln(sources[sourceNo]);
  debugMessln();

  debugMess("Function selected: ");
  debugMessln(functionNo);
  debugMessln(functions[functionNo]);
  debugMessln();

  debugMess("Volume: ");
  debugMess(volume);
  debugMessln("%");
  debugMess("Balance: ");
  debugMessln(balance);
  debugMessln();

  debugMess("FM radio frequency: ");
  debugMessln(frequency);
  /* commented out because TEA5767 doesn't seem to have this option
    debugMess("FM radio volume: ");
    debugMess(radioVolume);
  */
  debugMessln();

  /*******************************
    Define pins
  *******************************/
  lcd.setCursor(0, 1);
  lcd.print("Defining pins ...");

  debugMessln("Defining pins ...");
  debugMessln();

  pinMode(muxPin0, OUTPUT);
  pinMode(muxPin1, OUTPUT);
  digitalWrite(muxPin0, LOW);
  digitalWrite(muxPin1, LOW);

  pinMode(csPL, OUTPUT); // chip select for left channel potentiometer
  pinMode(csPR, OUTPUT); // chip select for right channel potentiometer
  digitalWrite(csPL, HIGH);
  digitalWrite(csPR, HIGH);

  pinMode(btMute, OUTPUT); // mute output on bluetooth module
  pinMode(btOn, OUTPUT);   // mute output on bluetooth module
  digitalWrite(btMute, HIGH);
  digitalWrite(btOn, LOW);

  delay(bootDelay); // delay to be able to see message on LCD

  /*******************************
    Starting SPI interface
  *******************************/
  lcd.setCursor(0, 1);
  lcd.print("Starting SPI ...");

  debugMessln("Starting SPI ...");
  debugMessln();

  SPI.begin();

  delay(bootDelay); // delay to be able to see message on LCD

  /*******************************
    Build custom characters
  *******************************/
  lcd.setCursor(0, 1);
  lcd.print("Building chars ...");

  debugMessln("Building custom characters ...");
  debugMessln();

  lcd.createChar(1, bar1);
  lcd.createChar(2, bar2);
  lcd.createChar(3, bar3);
  lcd.createChar(4, bar4);
  lcd.createChar(5, bar5);

  /*
    lcd.createChar(1, fill1);
    lcd.createChar(2, fill2);
    lcd.createChar(3, fill3);
    lcd.createChar(4, fill4);
    lcd.createChar(5, fill5);
  */

  delay(bootDelay); // delay to be able to see message on LCD

  /*******************************
    Set up rotary encoders
  *******************************/
  lcd.setCursor(0, 1);
  lcd.print("Setting up encoders ...");

#if DEBUG
  debugMessln("Setting up rotary encoders  ...");
  debugMessln();
#endif

  rotary1.setTrigger(HIGH); // set the trigger to be either a HIGH or LOW pin (Default: HIGH), note this sets all three pins to use the same state
  rotary1.setDebounceDelay(debounceDelay);
  rotary1.setErrorDelay(errorDelay);

  rotary2.setTrigger(HIGH);
  rotary2.setDebounceDelay(debounceDelay);
  rotary2.setErrorDelay(errorDelay);

  delay(bootDelay); // delay to be able to see message on LCD

  /*******************************
    Start FM radio receiver
  *******************************/
  lcd.setCursor(0, 1);
  lcd.print("Starting receiver ...");

  debugMessln("Starting FM radio receiver  ...");
  debugMessln();

  radio.init(); // initialize radio

#if DEBUG
  radio.debugEnable(); // enable information to the serial port
#endif

  setReceiver(); // tune the radio receiver

#if DEBUG
  printRadioDebugInfo();
#endif

  delay(bootDelay); // delay to be able to see message on LCD

  /*******************************
    Start DFPlayer Mini
  *******************************/
#if DFPLAYER
  lcd.setCursor(0, 1);
  lcd.print("Starting sw serial ...");

  debugMessln("Starting software serial  ...");
  debugMessln();

  mySoftwareSerial.begin(9600);

  delay(bootDelay); // delay to be able to see message on LCD
#endif

  /*******************************
    Fill LCD
  *******************************/
  printSource();
  printFunction();

  setVolume();

  debugMessln("Setup finished, entering main loop ...");
}

void loop()
{

  // ******************** handle buttons *******************
  readButtons();

  if (millis() - button1Millis >= screenWait) // return to home screen after wait time
  {
    functionNo = 0;
    sourceNo = selectSourceNo; // source might have been changed
  }

  if (millis() - button2Millis >= screenWait && sourceNo == 0 && presetScreen) // return to home screen after wait time
  {
    presetScreen = false;
    printFM();
  }

  // ******************* act on changes *******************
  /**********
   * radio frequency has changed
   **********/
  if (sourceNo == 0 && frequency != oldFrequency) // tune in to new radio frequency
  {
    setReceiver();
    oldFrequency = frequency;
  }

  /**********
   * function (Vol, Src, Bal) has changed
   **********/
  if (functionNo != oldFunctionNo) // new function for second row on LCD has been selected
  {
    printFunction();
    oldFunctionNo = functionNo;
  }

  /**********
   * volume has changed
   **********/
  if (volume != oldVolume && functionNo == 0) // volume has been changed
  {
    printVolume();
    setVolume();
    oldVolume = volume;
  }

  /**********
   * balance has changed
   **********/
  if (balance != oldBalance) // balance has been changed
  {
    printBalance();
    setVolume();
    oldBalance = balance;
  }

/**********
 * DFPlayer track number has changed
 **********/
#if DFPLAYER
  if (sourceNo == 3 && trackNo != oldTrackNo) // balance has been changed
  {
    printTrackNo();
    playTrackNo();
    oldTrackNo = trackNo;
  }
#endif

  /**********
   * source has changed
   **********/
  if (sourceNo != oldSourceNo) // new source has been selected
  {
    printSource();
    setMux(); // select source via multiplexer

    if (sourceNo == 0) // FM radio is selected
    {
      radio.setMute(false); // unmute the radio
      setReceiver();        // set frequency on receiver
    }
    else
    {
      radio.setMute(true); // mute the radio

      debugMessln("Radio muted");
      debugMessln();
    }

    if (sourceNo == 1) // bluetooth selected
    {
      digitalWrite(btMute, LOW); // unmute bluetooth
      digitalWrite(btOn, HIGH);  // power on the bluetooth module
    }
    else
    {
      digitalWrite(btMute, HIGH); // mute bluetooth
      digitalWrite(btOn, LOW);    // power off the bluetooth module

      debugMessln("Bluetooth muted and off");
      debugMessln();
    }

#if DFPLAYER
    if (sourceNo == 3) // DFPlayer selected
    {
      startDFPlayer(); // initiate DFPlayer
    }
    else
    {
      myDFPlayer.pause(); // pause the mp3

      debugMessln("DFPlayer paused");
      debugMessln();
    }
#endif

    if (functionNo == 1)
    {
      printSourceSelect();
    }

    oldSourceNo = sourceNo;
  }
}

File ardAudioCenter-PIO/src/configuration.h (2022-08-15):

#define programName "ardAudioCenter"
#define date "20220815"
#define author "Jon Sagebrand"
#define email "jonsagebrand@gmail.com"

/*******************************
  Enable DFPlayer
*******************************/
#define DFPLAYER 0 // set to 1 to enable DFPlayer

/*******************************
  Serial
*******************************/
#define serialSpeed 9600

#define bootDelay 100 // delay after each boot message

/*******************************
  Debugging
*******************************/
#define DEBUG 0 // debugMess is off when 0
#define INFO 1

#if DEBUG
#define debugMess(x) Serial.print(x)
#define debugMessln(x) Serial.println(x)
#else
#define debugMess(x)
#define debugMessln(x)
#endif

#if INFO || DEBUG
#define infoMess(x) Serial.print(x)
#define infoMessln(x) Serial.println(x)
#else
#define infoMess(x)
#define infoMessln(x)
#endif

/*******************************
  Wire I2C setup
*******************************/
#include <Wire.h>

// arduino: SDA -> A4, SCL -> A5
// nodemcu: SDA -> D2, SCL -> D1
//#define SDApin A4
//#define SCLpin A5

/*******************************
  FM radio module, TEA5767
*******************************/
#define useRDS 0

#include <radio.h>
#include <TEA5767.h>

#if useRDS
#include <RDSParser.h>
#endif

#define radioBand RADIO_BAND_FM // the band that will be tuned is FM

RADIO_FREQ preset[] = {
    // some radio presets
    9000,  // SR P1, Sörmland
    9480,  // SR P4 Östergötland
    9740,  // RIX FM, Nyköping
    9870,  // SR P3, Sörmland
    10020, // SR P4 Gotland
    10230, // SR P4 Sörmland
    10030, // SR P4 Gotland
    10300, // Star FM, Nyköping
    10330  // SR P4 Stockholm
};

#define FIX_BAND RADIO_BAND_FM

byte presetNo = 5;

double frequency = preset[presetNo]; // start frequency
double oldFrequency = frequency;

#define minFrequency 8750
#define maxFrequency 10800

#define frequencyStep 10

boolean presetScreen = false;
boolean presetActive = false;

// const byte radioVolume = 15; // volume output from the module, commented out because TEA5767 doesn't seem to have this option

// int search_mode = 0;
// int search_direction;

// unsigned long last_pressed;
// unsigned char buf[5];

// int stereo;
// int signal_level;

// int inByte;
// int flag = 0;

/*******************************
  LCD setup
*******************************/
#include <LiquidCrystal_I2C.h>

#define lcdColumns 16
#define lcdRows 2

LiquidCrystal_I2C lcd(0x27, lcdColumns, lcdRows); // set the LCD address to 0x27 for a 16 chars and 2 line display

#include "chars.h" // load custom characters

/*******************************
  Rotary encoders
*******************************/
#include <SimpleRotary.h>

SimpleRotary rotary1(2, 3, 4); // multi function button, CLK, DT, SW (pin A, pin B, button pin)
SimpleRotary rotary2(5, 6, 7); // radio button

#define debounceDelay 2 // set the debounce delay in ms, default 2
#define errorDelay 200  // set the error correction delay in ms, default 200

byte rotate1;
byte push1;

byte rotate2;
byte push2;

/*******************************
  Digital potentiometers, MCP41010
*******************************/
#include <SPI.h> // loads the SPI library

#define csPL 16 // CS (chip select for MCP41010, digital potentiometer), left channel volume, 16 => A2
#define csPR 17 // CS, right channel volume, 17 => A3

byte volL; // volume on left channel
byte volR; // volume on right channel

/*******************************
  Bluetooth module, JDY-62
*******************************/
#define btMute 8 // pin connected to mute input on JDY-62, muted when HIGH
#define btOn 12  // pin connected to MOSFET, powering the module when HIGH

/*******************************
  SD card module, DFPlayer Mini
*******************************/
#if DFPLAYER
#include <SoftwareSerial.h> // this library adds RX and TX to other pins than 0 and 1
#include <DFRobotDFPlayerMini.h>

SoftwareSerial mySoftwareSerial(10, 9); // RX, TX, on the DFPlayer 10 connects to TX and 9 to RX

DFRobotDFPlayerMini myDFPlayer; // define player

#define DFPlayerSerialTimeOut 500
#define DFPlayerVolume 10 // volume value (0~30)

#define DFPlayerEQ DFPLAYER_EQ_NORMAL // set different EQ
/*
DFPLAYER_EQ_NORMAL
DFPLAYER_EQ_POP
DFPLAYER_EQ_ROCK
DFPLAYER_EQ_JAZZ
DFPLAYER_EQ_CLASSIC
DFPLAYER_EQ_BASS
*/

#define DFPlayerDevice DFPLAYER_DEVICE_SD // set device we use SD as default
/*
DFPLAYER_DEVICE_U_DISK
DFPLAYER_DEVICE_SD
DFPLAYER_DEVICE_AUX
DFPLAYER_DEVICE_SLEEP
DFPLAYER_DEVICE_FLASH
*/

boolean DFPlayerPause = false; // DFPlayer is paused

int trackNo; // track number selected
int oldTrackNo;

/*
String sdBuf; // takes the characters sent over serial
boolean sdPause = false;
byte sdEqualizer = 0; // (0 = Normal, 1 = Pop, 2 = Rock, 3 = Jazz, 4 = Classic, 5 = Bass)
byte maxSDSongs = 0;
*/
#endif

/*******************************
  Sources
*******************************/
byte sourceNo = 0;
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

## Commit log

2020-05-26 first layout of schematics
    [ardAudioCenter.kicad_pcb, ardAudioCenter.sch]
2020-05-26 first sketch
    [configuration.h]
2020-05-27 sketch now changes function
    [configuration.h]
2020-05-27 encoder is read
    [configuration.h]
2020-05-27 volume up/down
    [configuration.h]
2020-05-28 now selects source
    [configuration.h]
2020-05-30 switched to arduino nano, now sets source and mux
    [ardAudioCenter.sch, configuration.h]
2020-05-30 now writes to potentiometers and sets balance
    [configuration.h]
2020-05-30 added volume bar
    [configuration.h]
2020-05-30 added radio and sd card modules
    [ardAudioCenter.sch, configuration.h]
2020-05-31 added bluetooth module
    [ardAudioCenter.sch, configuration.h]
2020-05-31 went back to arduino nano and added second encoder again
    [configuration.h]
2020-05-31 giving nodemcu another go
    [ardAudioCenter nodeMCU.sch, configuration.h]
2020-05-31 nah, no nodemcu
    [ardAudioCenter nodeMCU.sch, configuration.h]
2020-06-02 second rotary controls radio
    [configuration.h]
2020-06-03 pcb routing
    [ardAudioCenter.kicad_pcb, ardAudioCenter.sch]
2020-06-04 experimented with radio
    [configuration.h]
2020-06-04 pcb v1
    [ardAudioCenter.kicad_pcb, ardAudioCenter.sch]
2020-06-05 PCB v1.1
    [ardAudioCenter.kicad_pcb, ardAudioCenter.sch]
2020-06-10 changed bt hookup
    [ardAudioCenter.kicad_pcb, ardAudioCenter.sch]
2022-03-20 new pcb
    [ardAudioCenter.kicad_pcb, ardAudioCenter.kicad_sch]
2022-05-13 deleted kicad5
    [ardAudioCenter.sch]
2022-05-15 pcb, moved to pio
    [ardAudioCenter-ams1117.kicad_pcb, ardAudioCenter-ams1117.kicad_sch, ardAudioCenter.kicad_pcb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]
2022-05-16 2-layer PCB
    [ardAudioCenter-ams1117-autorouted.kicad_pcb, ardAudioCenter-ams1117-autorouted.kicad_sch, ardAudioCenter-ams1117.kicad_pcb]
2022-05-20 cleaned up code
    [configuration.h]
2022-05-20 minor changes
    [ardAudioCenter-ams1117-autorouted.kicad_sch, configuration.h]
2022-05-20 got the old arduino code back
    [configuration.h]
2022-05-21 added SPI as lib_dep
2022-05-21 added brackets, (), after SPI.begin
2022-05-21 correcting output on source select
    [main.cpp]
2022-05-21 DFPlayer work
    [configuration.h]
2022-05-22 now debug and info, more work on dfplayer
    [configuration.h]
2022-05-22 more DFPlayer work
    [configuration.h]
2022-05-22 new 3D
    [ardAudioCenter-ams1117-autorouted.kicad_pcb, ardAudioCenter-ams1117-autorouted.kicad_sch]
2022-05-23 possible to deselect DFPlayer
    [configuration.h]
2022-05-25 deleted old arduino ino files
    [configuration.h]
2022-05-26 Dual amplifier
    [DualTDA2005Amplifier.kicad_pcb, DualTDA2005Amplifier.kicad_sch]
2022-06-12 volume and steps
    [configuration.h]
2022-06-12 deleted schematics
    [ardAudioCenter-ams1117.kicad_pcb, ardAudioCenter-ams1117.kicad_sch]
2022-06-23 new volumes
    [configuration.h]
2022-08-14 bluetooth controlled with MOSFET
    [configuration.h]
2022-09-01 atmega pcb
    [ATmega328.kicad_sch, ardAudioCenter-ATmega328.kicad_pcb, ardAudioCenter-ATmega328.kicad_sch]
